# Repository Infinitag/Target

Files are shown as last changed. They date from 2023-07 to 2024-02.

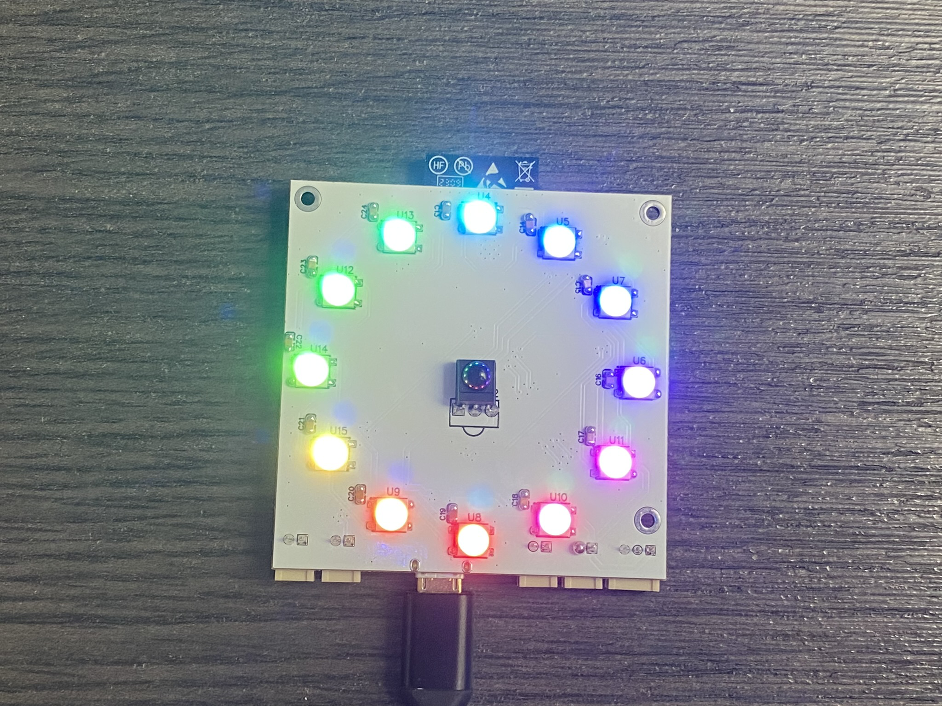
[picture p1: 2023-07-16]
Images/target_front_on.jpeg

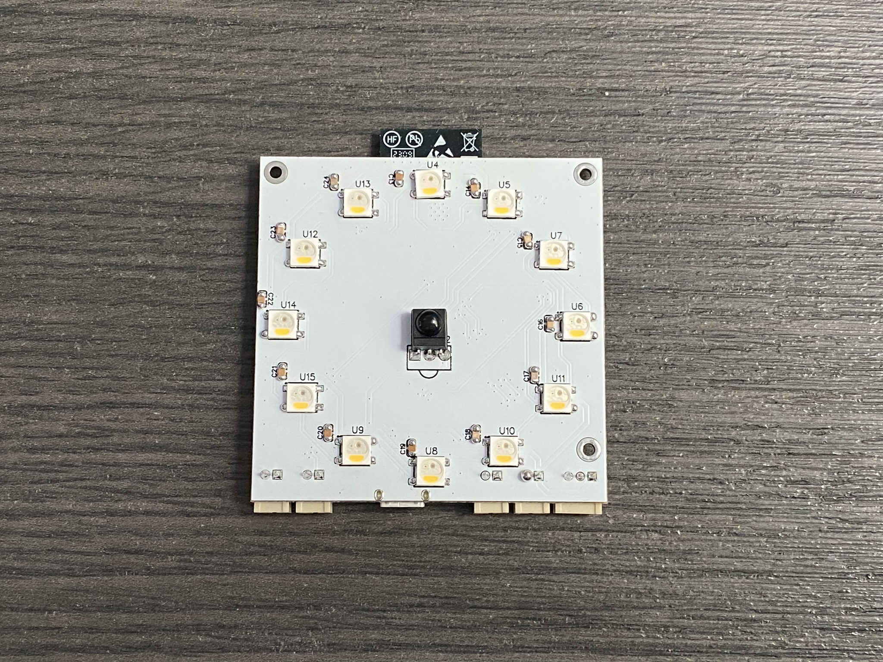
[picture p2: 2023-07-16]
Images/target_front.jpeg

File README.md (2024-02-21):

# Infinitag Target
[][cc-by-nc-sa] 

The Infinitag Target is a hit target for the Infinitag system based on an ESP32 S3 module. 
The target has the following functions:

- 12 individually controllable RGBW LEDs on the front for a status display.
- IR receivers to receive the signals
- One switchable 5V connector
- One switchable 3.3V connector
- One switches to pass the incoming signal
- Power supply port
- Extension port for additional external LEDs

## Software

In the "ArduinoCode" directory is the source code as .ino file for the Arduino IDE to upload to the taget board.

### Preparation

In order for the board to be recorded successfully, you must first add another source in the settings for the board management:

```
https://dl.espressif.com/dl/package_esp32_index.json
```

The board uses the CP2102N chipset to program the ESP32.
Please check in your device management if you have installed an appropriate driver on your device.
If not, install the appropriate driver, so that the Arduino IDE recognizes the target board.

### Settings

The following must be selected as the board for the upload:
ESP32 Arduino > ESP32 S3 Dev Module

### Libraries

- esp32 by Espressif Systems v 2.0.11 (3.0.0 not working with IRremote)
- IRremote by shirriff v 4.2.0

## Hardware

### PCB

We have published all files for the PCB incl. schematic, PCB design and BOM here:

https://oshwlab.com/crusher/infinitag-target

### 3D files

The files for a 3D enclosure can be found in the folder "Hardware/3DFiles".

Additionally you can find the latest version under the following link:

https://a360.co/3NOv182

## License
This work is licensed under a
[Creative Commons Attribution-NonCommercial-ShareAlike 4.0 International License][cc-by-nc-sa].

[][cc-by-nc-sa]

[cc-by-nc-sa]: http://creativecommons.org/licenses/by-nc-sa/4.0/
[cc-by-nc-sa-image]: https://licensebuttons.net/l/by-nc-sa/4.0/88x31.png
[cc-by-nc-sa-shield]: https://img.shields.io/badge/License-CC%20BY--NC--SA%204.0-lightgrey.svg

## Additional

For more information about the Infinitag System please visit [infinitag.io](http://www.infinitag.io).

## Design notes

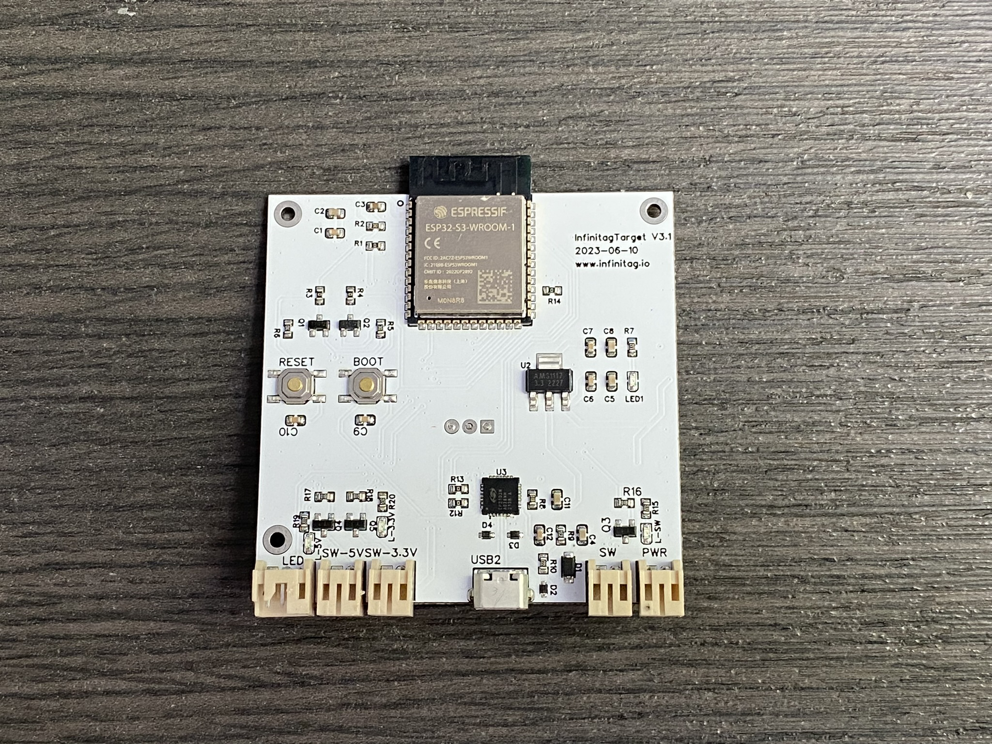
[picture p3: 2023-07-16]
Images/target_back.jpeg

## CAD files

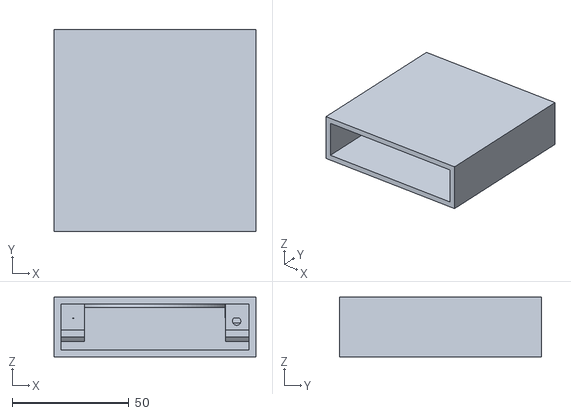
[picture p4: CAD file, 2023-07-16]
Hardware/3DFiles/Shell.stl
86.6 x 86.6 x 25.6

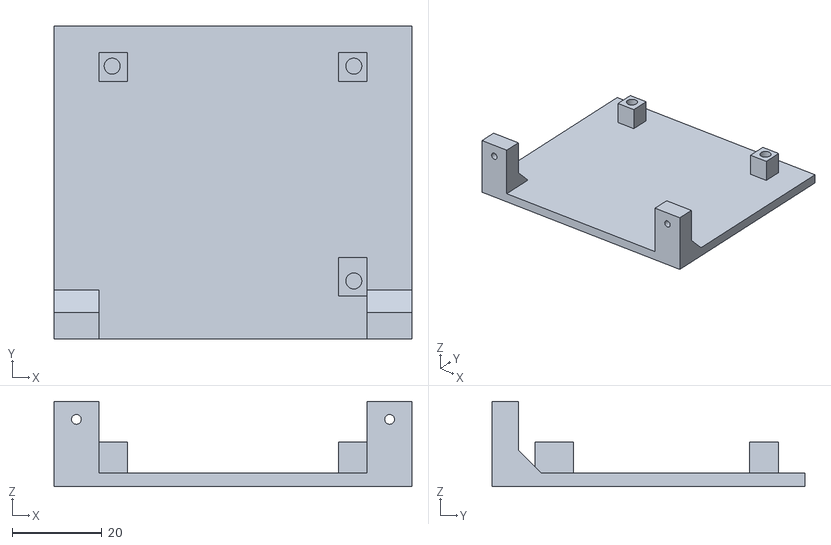
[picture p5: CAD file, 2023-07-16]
Hardware/3DFiles/Slide.stl
80.0 x 70.0 x 19.0

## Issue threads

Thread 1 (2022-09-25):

Update PCB

SkHCrusher, 2022-09-25:
The schema files have already been adapted to the current state, but these changes are still missing in the PCB layout.
The following ToDos are open here:
- [ ] The IR receiver now works with 3.3V instead of 5V
- [ ] Capacitor to solve sketch upload issues added (https://forum.arduino.cc/t/solved-esp32-problem-with-sketch-upload/1033894)
- [ ] Solder jumper added to disable ESP32 serial output
- [ ] External pin connector extended by 5V and 3.3V as well as GND
- [ ] Update JLCPCB files

SkHCrusher, 2023-07-16:
Solved with https://github.com/Infinitag/Target/pull/3

Closed 2023-07-16.

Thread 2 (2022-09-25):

Boot problems without USB

SkHCrusher, 2022-09-25:
Currently the target board works via USB. As soon as the board is supplied with an external power supply via the connector socket, the code does not boot and the board remains motionless.

This problem was solved at the beginning, since here with a serial connection was worked, which is not available without USB however.

Currently the problem is also without serial outputs again. Here I do not have a solution at present yet.

In the following forum the problem was described and I hope here for a solution:
https://forum.arduino.cc/t/reopen-esp32-boot-problem-without-usb/1033499/17

SkHCrusher, 2023-07-16:
Solved with #3

Closed 2023-07-16.

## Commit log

2022-09-25 Current Version
2022-09-25 KiCad6 PCB Project
    [ESP32_programmer.kicad_sch, arduinoNanoV3.kicad_sch, esp32.kicad_sch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]
2022-09-25 Files for JLCPCB
    [target.csv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]
2022-09-25 Correct folder structure for Arduino IDE + update Readme
2022-09-28 PCB Update from current schema
    [ESP32_programmer.kicad_sch, target.kicad_pcb, target.kicad_sch]
2022-09-29 PCB files with current changes updated
    [target-B_Cu.gbl, target-B_Mask.gbs, target-B_Paste.gbp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]
2023-07-16 Update target source code to v3.1.0
    Complete redesign with a esp32 S3 dual core chip + new PCB design and trigger four sound effects
2023-07-16 Remove old hardware files
    [ESP32_programmer.kicad_sch, arduinoNanoV3.kicad_sch, esp32.kicad_sch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]
2023-07-16 3D files for the case
    [Shell.stl, Slide.stl]
2023-07-16 Add new build for esp32 s3
2023-07-18 Correct version of the code (3.1 was version of the pcb)
2024-02-22 Switch from Arduino IDE to VisualStudio Code with PlatformIO

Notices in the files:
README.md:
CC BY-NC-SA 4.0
